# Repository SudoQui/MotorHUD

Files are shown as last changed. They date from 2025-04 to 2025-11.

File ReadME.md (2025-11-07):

# 🏍️ MotorHUD

<p align="center">
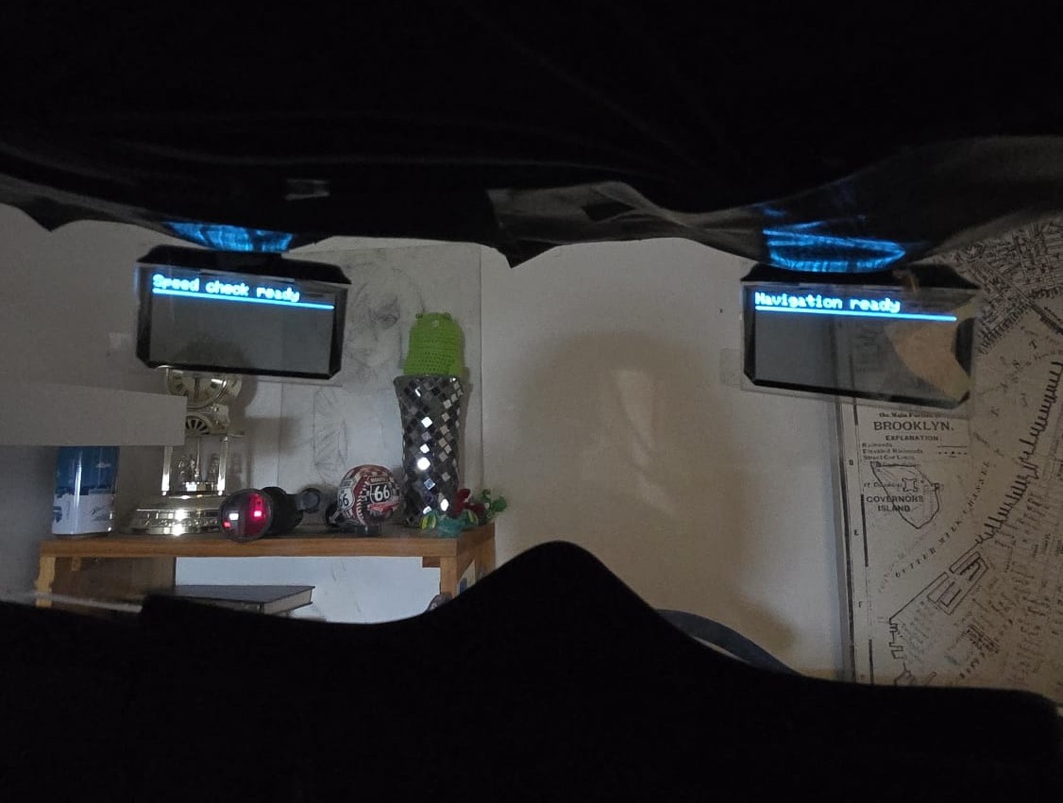
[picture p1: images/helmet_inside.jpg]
MotorHUD inside helmet
  
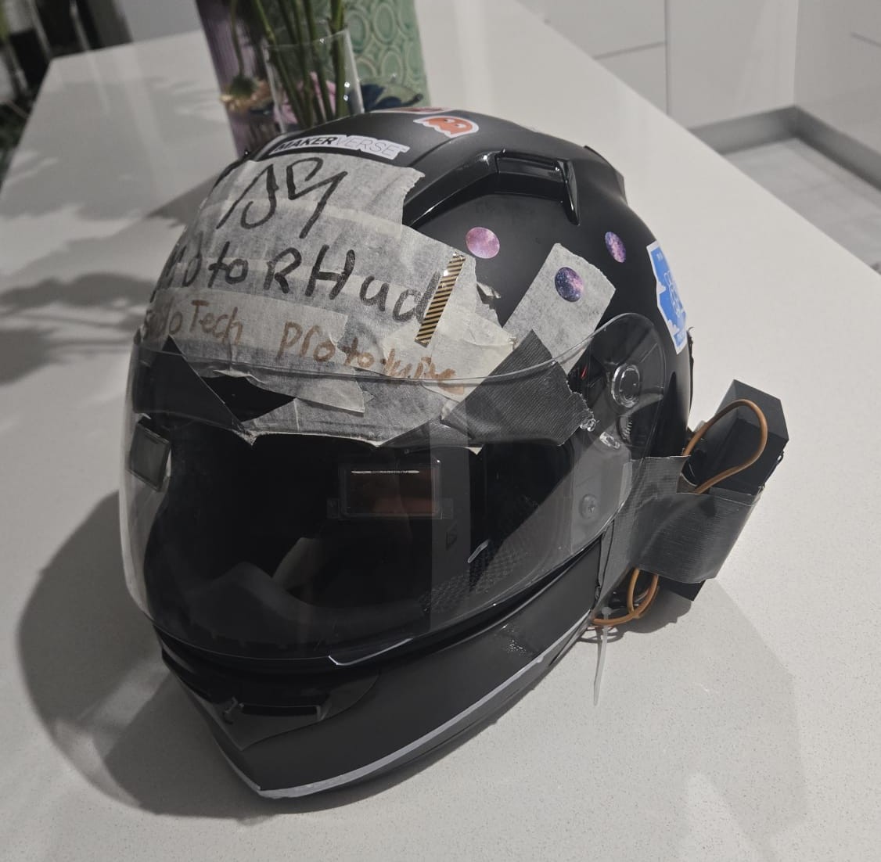
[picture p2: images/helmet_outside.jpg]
MotorHUD outside view
  
</p>

MotorHUD shows the next turn and the current speed zone inside the helmet so your eyes stay on the road.  
This repo covers the helmet side. It includes the ESP32 hub firmware, a simple Android companion app starter, and printable case parts.  
The speed-sign vision stack lives in a separate repo named **SudoSpeed**. The display now uses transparent OLEDs for better integration and readability.

---

## Repo layout

```
Companion App/            Android starter for BLE and Directions
images/                   All images go here
Case.stl                  ESP32 and powerbank case
display_cover v1.stl      Display cover and helmet mount
Lid v1.stl                Lid for the cover
Esp32_code.cpp            ESP32 main firmware
SudoSpeed.py              Optional helper or bridge
README.md                 This file
LICENSE                   MIT license
```

---

## How it works

```
Phone Companion App → BLE text "NAV:<instruction>"
SudoSpeed on Pi or laptop → Classic BT SPP text "Z:<kph>"
ESP32 hub receives both → draws Navigation on left OLED and Zone on right OLED
Transparent OLEDs inside the visor present minimal, high-contrast text
```

Typical messages  
* From phone: `NAV:Turn left onto Hurley Street`  
* From SudoSpeed: `Z:60`

---

## Hardware overview

* Two 128×64 transparent OLEDs on shared SPI  
* ESP32 as the hub  
* Power from a small USB battery bank or bike 5 V regulator with fuse

**Pin diagram image**  
Upload your diagram as `images/pin_diagram.png` and it will appear here

<p align="center">
  ESP32 pin diagram
</p>

---

## Part A. ESP32 firmware

**File**  
`Esp32_code.cpp`

**Build steps**
1. Use Arduino IDE or PlatformIO  
2. Install ESP32 boards package  
3. Add libraries: Adafruit GFX, Adafruit SSD1306, BluetoothSerial, NimBLE-Arduino  
4. Flash to the board and open Serial Monitor

**First run**
* Screens show waiting text  
* Device advertises as `ESP32-SUDOSPEED` for Classic BT and a BLE UART name for the phone  
* Any line that starts with `NAV:` or `Z:` updates the display

---

## Part B. SudoSpeed link on Raspberry Pi

**Goal**  
Run SudoSpeed and forward zone updates to the ESP32.

**Steps**
1. Pair the Pi with the ESP32 over Classic Bluetooth SPP  
2. Run SudoSpeed with camera or a test clip  
3. Pipe lines that start with `Z:` to the SPP device

Relay example

```python
# relay_z_to_spp.py
import serial, sys
ser = serial.Serial("/dev/rfcomm0", 115200, timeout=1)
for line in sys.stdin:
    if line.startswith("Z:"):
        ser.write((line.strip() + "\n").encode("utf-8"))
```

Run

```bash
python3 run_speed_reader.py --source 0 --det detect.onnx --rec classify.onnx |
python3 relay_z_to_spp.py
```

You can also keep a small helper in `SudoSpeed.py` if you prefer a single entry point.

---

## Part C. Companion App

**Folder**  
`Companion App/`

**What it does**  
Gets GPS on the phone, calls the Google Directions API, reduces to the single next instruction, and sends `NAV:<text>` over BLE every few seconds. Re-routes if the rider turns away from the path.

**Setup**
1. Open in Android Studio  
2. Add your Directions API key  
3. Grant location and Bluetooth permissions  
4. Pair with the ESP32 and start

---

## Printing and assembly

**STLs**  
`Case.stl`, `display_cover v1.stl`, `Lid v1.stl`

**Notes**
1. Print in ABS or PETG for heat and weather  
2. Use small zip ties or M2 screws to secure the transparent OLED in the cover  
3. Route cables along the helmet edge and through the case grooves  
4. Test at night and in bright daylight before riding

---

## Images

Keep every photo in the images folder. Planned additions:

```
images/
  helmet_inside.png
  helmet_outside.png
  pi_case_final.png
  pin_diagram.png
```

Add more as needed and reference them directly from this folder.

---

## Safety

MotorHUD is a research and learning project. Test off-road first and always follow road rules.

---

## License

MIT. See `LICENSE` in this repo.

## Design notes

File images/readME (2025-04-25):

images of motorHUD showcasing components, display and through display

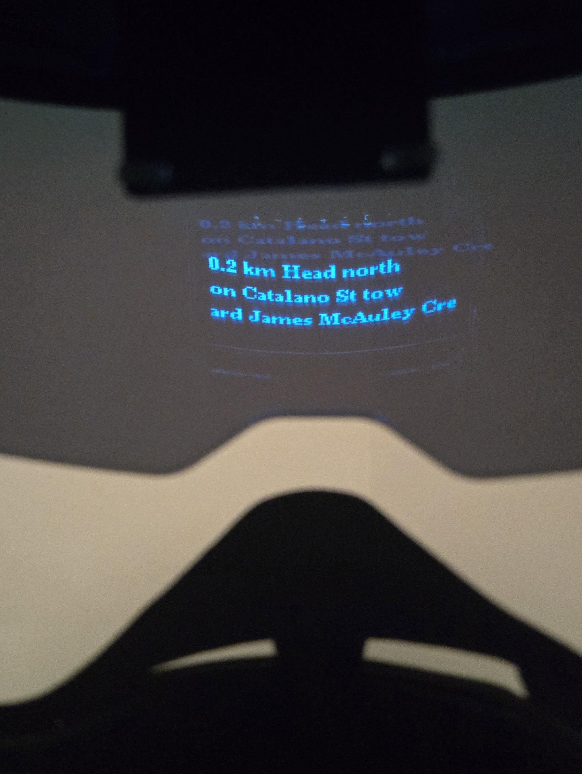
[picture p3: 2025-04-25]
images/POV.jpg

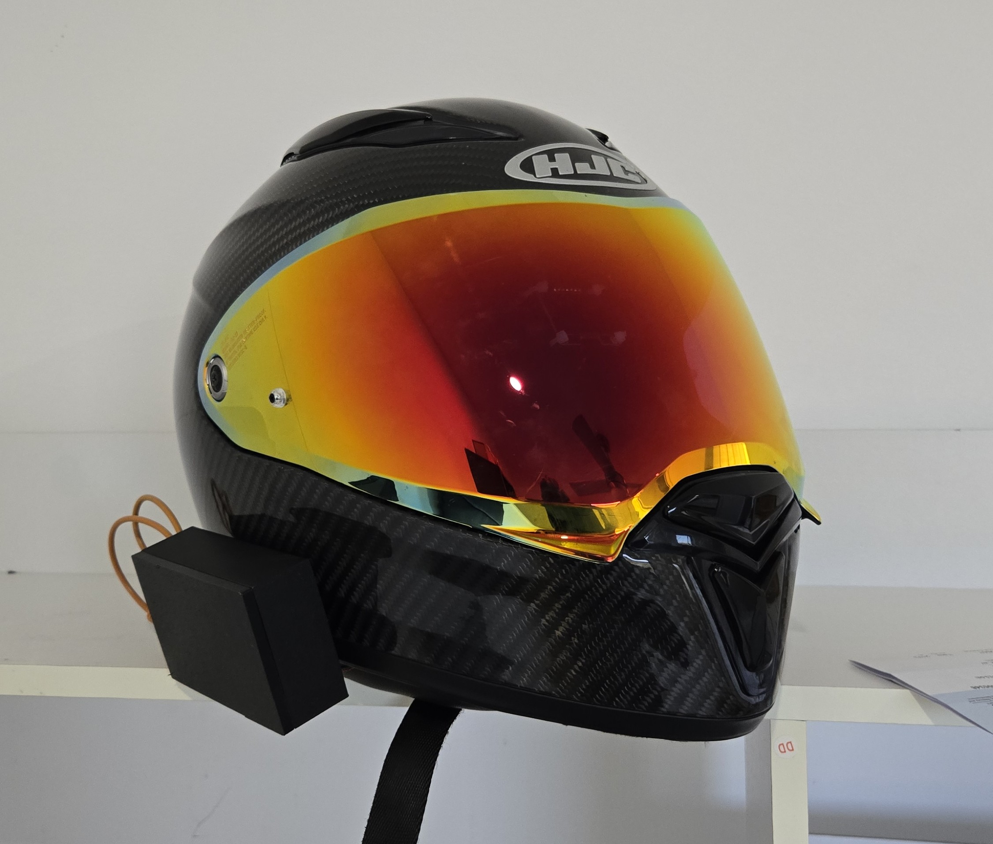
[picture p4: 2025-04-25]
images/display.jpg

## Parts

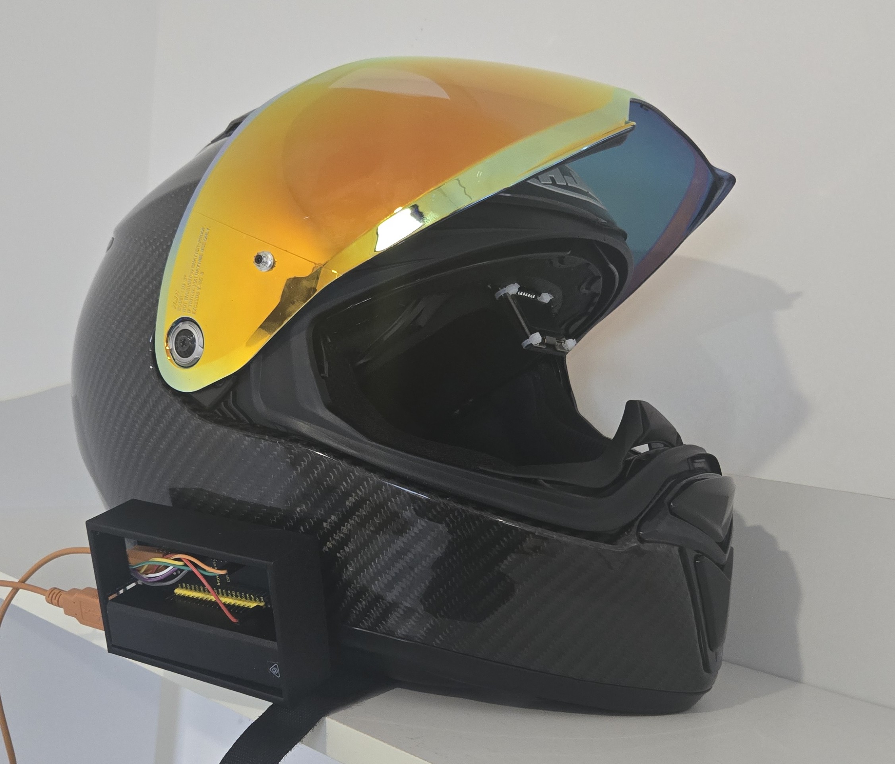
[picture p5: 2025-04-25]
images/components.jpg

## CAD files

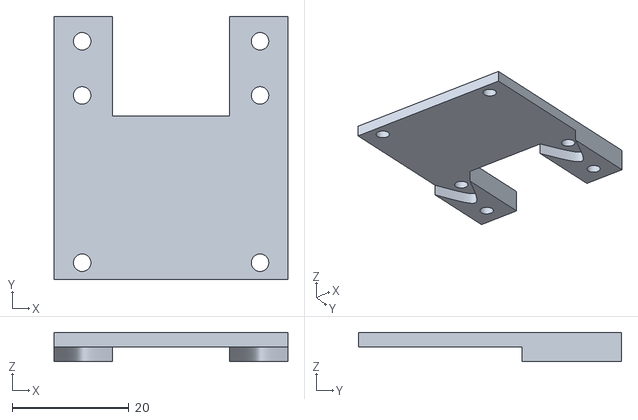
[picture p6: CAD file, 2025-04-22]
display_cover v1.stl
40.0 x 45.0 x 5.00

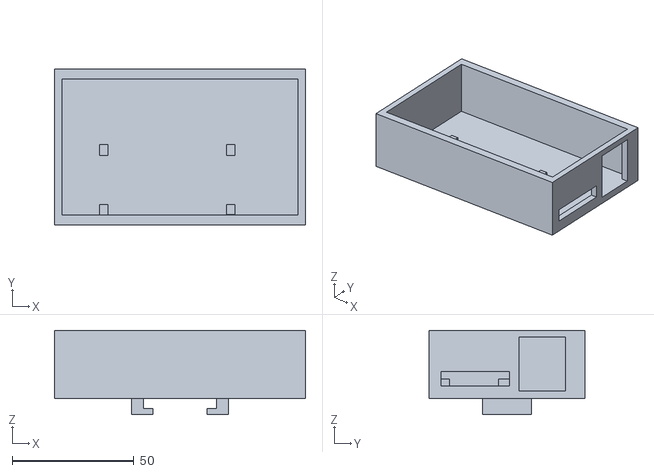
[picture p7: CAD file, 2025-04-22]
Case.stl
103.0 x 64.0 x 34.5

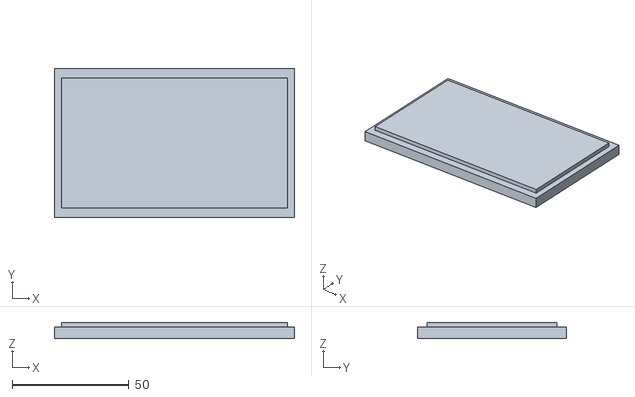
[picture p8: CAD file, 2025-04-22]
Lid v1.stl
103.0 x 64.0 x 7.00

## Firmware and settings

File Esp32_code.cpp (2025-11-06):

#include <SPI.h>
#include <Adafruit_GFX.h>
#include <Adafruit_SSD1306.h>
#include "BluetoothSerial.h"

#include <BLEDevice.h>
#include <BLEServer.h>
#include <BLEUtils.h>
#include <BLE2902.h>

// OLED pins
#define OLED_MOSI 23
#define OLED_CLK  18
// Left OLED
#define OLED1_DC   16
#define OLED1_CS    5
#define OLED1_RST  17
// Right OLED
#define OLED2_DC    4
#define OLED2_CS   14
#define OLED2_RST  27

Adafruit_SSD1306 dispLeft (128, 64, &SPI, OLED1_DC, OLED1_RST, OLED1_CS);
Adafruit_SSD1306 dispRight(128, 64, &SPI, OLED2_DC, OLED2_RST, OLED2_CS);


volatile int   g_zone  = -1;
volatile int   g_speed = -1;
String         g_nav1  = "";
String         g_nav2  = "";


unsigned long  tBlink   = 0;
bool           blinkOn  = false;


BluetoothSerial SPP;
String sppBuf;

// BlueDroid Connection
static BLEUUID SVC_UUID("6E400001-B5A3-F393-E0A9-E50E24DCCA9E");
static BLEUUID RX_UUID ("6E400002-B5A3-F393-E0A9-E50E24DCCA9E");
static BLEUUID TX_UUID ("6E400003-B5A3-F393-E0A9-E50E24DCCA9E");

BLEServer*         pServer = nullptr;
BLECharacteristic* pChrRX  = nullptr;
BLECharacteristic* pChrTX  = nullptr;

String bleBuf;

// Forward decls
void handleLine(String line, bool fromBLE);
void setNavText(const String& txt);
void showWaitingScreen();

// Display orientation
void setDisplayOrientation(Adafruit_SSD1306& d, bool rotate180, bool mirrorX, bool mirrorY) {
  d.setRotation(rotate180 ? 2 : 0);
  d.ssd1306_command(mirrorX ? 0xA1 : 0xA0); 
  d.ssd1306_command(mirrorY ? 0xC8 : 0xC0);
}

//BLE callbacks
class RxCallbacks : public BLECharacteristicCallbacks {
  void onWrite(BLECharacteristic* pChar) override {
    auto v = pChar->getValue();
    for (size_t i = 0; i < v.length(); ++i) {
      char ch = v[i];
      if (ch=='\n' || ch=='\r') {
        if (bleBuf.length()) { handleLine(bleBuf, true); bleBuf=""; }
      } else {
        bleBuf += ch;
        if (bleBuf.length()>256) bleBuf.remove(0, bleBuf.length()-256);
      }
    }
  }
};

class ServerCallbacks : public BLEServerCallbacks {
  void onConnect(BLEServer* pServer) override {
    Serial.println("[BLE] Central connected");
  }
  void onDisconnect(BLEServer* pServer) override {
    Serial.println("[BLE] Central disconnected");
    BLEDevice::getAdvertising()->start();
  }
};

void bleNotify(const String& s) {
  if (!pChrTX) return;
  pChrTX->setValue((uint8_t*)s.c_str(), s.length());
  pChrTX->notify();
}

//Text helpers
void setNavText(const String& txt) {
  String t = txt; t.trim();
  auto split = [](const String& s, int maxChars){
    String a = s; a.trim();
    if ((int)a.length() <= maxChars) return std::pair<String,String>(a,"");
    int cut = maxChars;
    for (int i=min(maxChars,(int)a.length()-1); i>=0; --i) if (a[i]==' '){ cut=i; break; }
    String l1 = a.substring(0, cut);
    String l2 = a.substring(cut); l2.trim();
    if ((int)l2.length() > maxChars) l2 = l2.substring(0, maxChars-1) + "…";
    return std::pair<String,String>(l1,l2);
  };
  auto p = split(t, 20);
  g_nav1 = p.first; g_nav2 = p.second;
}

void handleLine(String line, bool fromBLE){
  line.trim();
  if (!line.length()) return;

  // Allow "SPD:63|<nav>"
  if (line.startsWith("SPD:") && line.indexOf('|')>0) {
    int bar = line.indexOf('|');
    String sp = line.substring(4, bar);
    String nv = line.substring(bar+1);
    g_speed = sp.toInt();
    nv.replace("|"," | ");
    setNavText(nv);
    return;
  }

  if (line.startsWith("Z:")) {
    int z = line.substring(2).toInt();
    if (z>0 && z<200) g_zone = z;
  } else if (line.startsWith("SPD:")) {
    g_speed = line.substring(4).toInt();
  } else if (line.startsWith("NAV:")) {
    setNavText(line.substring(4));
  } else if (line == "PING") {
    if (fromBLE) bleNotify("PONG\n"); else SPP.println("PONG");
  }
}

//Minimal drawing
void drawNavMinimal() {
  dispLeft.clearDisplay();
  dispLeft.setTextColor(SSD1306_WHITE);
  
  dispLeft.setTextSize(2);
  dispLeft.setCursor(0, 8);
  if (g_nav1.length()) dispLeft.println(g_nav1);
  if (g_nav2.length()) {
    dispLeft.setCursor(0, 36);
    dispLeft.println(g_nav2);
  }
  dispLeft.display();
}

void drawZoneMinimal() {
  dispRight.clearDisplay();
  dispRight.setTextColor(SSD1306_WHITE);

  String z = (g_zone>0) ? String(g_zone) : String("--");
  dispRight.setTextSize(3);
  int x = (128 - (z.length()*18)) / 2;
  if (x < 0) x = 0;
  int y = 16;
  dispRight.setCursor(x, y);
  dispRight.print(z);

  bool over = (g_zone>0 && g_speed>=0 && g_speed>g_zone);
  if (over && blinkOn) {
    dispRight.drawCircle(64, 32, 27, SSD1306_WHITE);
  }

  dispRight.display();
}

// Waiting screen
void showWaitingScreen() {
  // LEFT
  dispLeft.clearDisplay();
  dispLeft.setTextColor(SSD1306_WHITE);
  dispLeft.setTextSize(1);
  dispLeft.setCursor(0, 0);
  dispLeft.println("Navigation ready");
  dispLeft.drawLine(0, 10, 127, 10, SSD1306_WHITE);
  dispLeft.display();

  // RIGHT
  dispRight.clearDisplay();
  dispRight.setTextColor(SSD1306_WHITE);
  dispRight.setTextSize(1);
  dispRight.setCursor(0, 0);
  dispRight.println("Speed check ready");
  dispRight.drawLine(0, 10, 127, 10, SSD1306_WHITE);
  dispRight.display();
}

// Setup
void setup() {
  Serial.begin(115200);
  delay(100);

  // SPI + OLEDs
  SPI.begin(OLED_CLK, -1, OLED_MOSI, OLED1_CS);
  if (!dispLeft.begin(SSD1306_SWITCHCAPVCC))  { Serial.println("Left OLED fail"); while(1)delay(1000); }
  setDisplayOrientation(dispLeft,  /*rotate180=*/false, /*mirrorX=*/false, /*mirrorY=*/false);

  delay(200);
  if (!dispRight.begin(SSD1306_SWITCHCAPVCC)) { Serial.println("Right OLED fail"); while(1)delay(1000); }
  setDisplayOrientation(dispRight, /*rotate180=*/false, /*mirrorX=*/false, /*mirrorY=*/false);

  // Waiting screen, elevator music type thing
  showWaitingScreen();

  // Classic SPP for Pi
  if (!SPP.begin("ESP32-SUDOSPEED")) { Serial.println("SPP init fail"); while(1)delay(1000); }
  Serial.println("SPP ready for Pi");

  // BLE (Bluedroid) for phone
  BLEDevice::init("MotorHUD BLE");
  BLEDevice::setMTU(247);

  pServer = BLEDevice::createServer();
  pServer->setCallbacks(new ServerCallbacks());

  BLEService* pSvc = pServer->createService(SVC_UUID);

  pChrTX = pSvc->createCharacteristic(TX_UUID, BLECharacteristic::PROPERTY_NOTIFY);
  pChrTX->addDescriptor(new BLE2902());

  pChrRX = pSvc->createCharacteristic(RX_UUID,
              BLECharacteristic::PROPERTY_WRITE | BLECharacteristic::PROPERTY_WRITE_NR);
  pChrRX->setCallbacks(new RxCallbacks());

  pSvc->start();

  BLEAdvertising* adv = BLEDevice::getAdvertising();
  adv->addServiceUUID(SVC_UUID);
  adv->setScanResponse(true);
  adv->start();
}


void loop() {

  while (SPP.available()) {
    char ch = SPP.read();
    if (ch=='\n' || ch=='\r') {
      if (sppBuf.length()) { handleLine(sppBuf, false); sppBuf=""; }
    } else {
      sppBuf += ch;
      if (sppBuf.length()>256) sppBuf.remove(0, sppBuf.length()-256);
    }
  }

  unsigned long now = millis();
  if (now - tBlink >= 450) { tBlink = now; blinkOn = !blinkOn; }

  static unsigned long tDraw = 0;
  if (now - tDraw >= 120) {
    tDraw = now;

    if (g_nav1.length() || g_nav2.length()) drawNavMinimal();

    if (g_zone > 0) drawZoneMinimal();
  }

  delay(4);
}

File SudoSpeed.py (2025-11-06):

import os
os.environ.setdefault("ORT_LOG_SEVERITY_LEVEL", "3")

import time, threading, subprocess, cv2, numpy as np
from collections import deque, defaultdict
from ultralytics import YOLO

# SER CONFIG
DETECT_WEIGHTS = "/home/sudospeed/models/detect_best.onnx"   # detect (320x320)
REC_WEIGHTS    = "/home/sudospeed/models/rec_best.onnx"      # classify (64x64)
DETECT_IMGSZ   = 320
IMG_SIZE_CLS   = 64

USE_CAMERA  = True
CAM_SIZE    = (960, 544) 
VIDEO_PATH  = "" 


OLED_ENABLED = True
SPI_PORT    = 0
SPI_DEVICE  = 0 
OLED_DC     = 25
OLED_RST    = 24
OLED_WIDTH  = 128
OLED_HEIGHT = 64

# Button
BTN_ENABLED  = True
BTN_PIN      = 17
DEBOUNCE_S   = 0.05
LONG_PRESS_S = 1.2

# ESP32 Bluetooth SPP
ESP32_MAC       = "FC:E8:C0:D6:2B:42"   # <-- your ESP32 MAC
RFCOMM_CHANNEL  = 1
SERIAL_PORT     = "/dev/rfcomm0"
SERIAL_BAUD     = 115200
SERIAL_RETRY_S  = 3.0
SERIAL_PREFIX   = "Z:"
HANDSHAKE_LINE  = "HELLO:CONNECTION_SECURED"


# I honestly dont even know how to tweak this to be optimal for each machine



# Detector
PROCESS_EVERY_N     = 2 
MAX_CROPS_PER_FRAME = 3
CONF_DET_THRESH     = 0.28
MIN_BOX_H_FRAC      = 0.025
RIGHT_SIDE_FRAC     = 0.20
ASPECT_MIN, ASPECT_MAX = 0.55, 1.5

# If this doesnt kill the latency issue, that it has killed me

CONF_THR                   = 0.65
TARGET_WINDOW_SEC_AT_30FPS = 0.8
CONFIRM_HITS               = 2   
EXTRA_HITS_TO_CHANGE       = 1 
COOLDOWN_S                 = 2.0
MAX_GAP_ANY_SIGN_S         = 60.0
DEFAULT_ZONE               = None

# Optional strong-confidence shortcut
ALLOW_STRONG_PROMOTE = True
STRONG_CONF_THR      = 0.93
STRONG_MIN_H_FRAC    = 0.04

#JUST KILL ME

DRAW_EVERY = 2  
PRINT_FPS_EVERY = 60  

#GLOBAL STATE
running = False
tx_enabled = False
current_zone, zone_set_ts = None, -1e18
pending_votes = defaultdict(lambda: deque(maxlen=64))
last_seen = {}
stop_event = threading.Event()

#Display
class OledHUD:
    def __init__(self, enable=True):
        self.device = None
        self.enable = enable
        if not enable:
            return
        try:
            from luma.core.interface.serial import spi
            from luma.oled.device import sh1106, ssd1306
            self.serial = spi(port=SPI_PORT, device=SPI_DEVICE, gpio_DC=OLED_DC, gpio_RST=OLED_RST, bus_speed_hz=8000000)
            try:
                self.device = sh1106(self.serial, width=OLED_WIDTH, height=OLED_HEIGHT)
                print("[OLED] SH1106")
            except Exception:
                self.device = ssd1306(self.serial, width=OLED_WIDTH, height=OLED_HEIGHT)
                print("[OLED] SSD1306")
        except Exception as e:
            print(f"[OLED] init failed: {e}")
            self.enable = False
            self.device = None

    def draw_lines(self, lines):
        if not (self.enable and self.device): return
        from PIL import Image, ImageDraw, ImageFont
        try:
            f = ImageFont.truetype("/usr/share/fonts/truetype/dejavu/DejaVuSans.ttf", 12)
        except Exception:
            from PIL import ImageFont
            f = ImageFont.load_default()
        W,H = self.device.width, self.device.height
        img = Image.new("1",(W,H),0); d = ImageDraw.Draw(img)
        y = 0
        for line in lines[:5]:
            d.text((0,y), line, fill=255, font=f); y += 12
        self.device.display(img)

    def draw_status(self, zone, cand, hits, cooldown, fps):
        if not (self.enable and self.device): return
        from PIL import Image, ImageDraw, ImageFont
        try:
            font_s = ImageFont.truetype("/usr/share/fonts/truetype/dejavu/DejaVuSans.ttf", 11)
            font_b = ImageFont.truetype("/usr/share/fonts/truetype/dejavu/DejaVuSans.ttf", 16)
        except Exception:
            from PIL import ImageFont
            font_s = ImageFont.load_default(); font_b = ImageFont.load_default()
        W,H = self.device.width, self.device.height
        img = Image.new("1",(W,H),0); d = ImageDraw.Draw(img)
        d.text((0,0),  f"FPS  : {fps:>4.1f}",                255, font=font_s)
        d.text((0,12), f"CAND : {cand if cand else '—'}",    255, font=font_s)
        d.text((0,24), f"HITS : {hits:>2}",                  255, font=font_s)
        d.text((0,36), f"COOL : {'Y' if cooldown else 'N'}", 255, font=font_s)
        z = str(zone) if zone is not None else "—"
        tz = f"Z:{z}"
        bx0,by0,bx1,by1 = d.textbbox((0,0), tz, font=font_b)
        tw,th = bx1-bx0, by1-by0
        x = max(0, W-tw-2); y = H-th-2
        d.rectangle((x-2,y-2,W,H), outline=255, fill=0)
        d.text((x,y), tz, 255, font=font_b)
        self.device.display(img)

oled = OledHUD(OLED_ENABLED)

# SERIAL Connection
class SerialTX:
    def __init__(self, port, baud, retry_s=3.0):
        self.port, self.baud, self.retry_s = port, baud, retry_s
        self.ser = None
        self.lock = threading.Lock()
        self._stop = False
        threading.Thread(target=self._open_loop, daemon=True).start()

    def _open_loop(self):
        while not self._stop:
            if self.ser is None:
                try:
                    import serial
                    self.ser = serial.Serial(self.port, self.baud, timeout=0.2)
                    print(f"[SERIAL] Connected -> {self.port} @ {self.baud}")
                except Exception:
                    time.sleep(self.retry_s); continue
            time.sleep(self.retry_s)

    def send(self, line):
        with self.lock:
            if self.ser is None: return False
            try:
                self.ser.write((line+"\n").encode("utf-8"))
                return True
            except Exception:
                try: self.ser.close()
                except Exception: pass
                self.ser = None
                return False

    def force_reopen(self):
        with self.lock:
            if self.ser:
                try: self.ser.close()
                except Exception: pass
                self.ser = None

    def close(self):
        self._stop = True
        with self.lock:
            if self.ser:
                try: self.ser.close()
                except Exception: pass
                self.ser = None

serial_tx = SerialTX(SERIAL_PORT, SERIAL_BAUD, SERIAL_RETRY_S)

def ensure_rfcomm_bound(mac, ch):
    try:
        subprocess.run(["sudo","rfcomm","release","0"], check=False,
                       stdout=subprocess.DEVNULL, stderr=subprocess.DEVNULL)
        subprocess.run(["sudo","rfcomm","bind","0", mac, str(ch)], check=True)
        print(f"[RFCOMM] /dev/rfcomm0 bound -> {mac} ch {ch}")
        return True
    except Exception as e:
        print(f"[RFCOMM] bind failed: {e}")
        return False
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

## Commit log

2025-04-20 Adding images, and having instructions to esp32 added on main page
2025-04-22 Add files via upload
    Adding 3d files for mounting
    [Case.stl, Lid v1.stl, display_cover v1.stl]
2025-11-06 Create MotorHudApp
2025-11-06 Revise README.md for MotorHUD project updates
    Updated README.md to reflect new features and integration with SudoSpeed. Enhanced clarity on project structure and installation steps.
